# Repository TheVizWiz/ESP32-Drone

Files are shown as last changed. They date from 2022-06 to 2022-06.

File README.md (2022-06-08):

# ESP32 - Drone

### A Drone, Controller, and Flight Software, based on the popular ESP32 Microcontroller architecture.

## Current State
- Drone:  CAD model has been finalized and printed, as shown below. RF24 modules have been tested at distance, and motors and batteries have been mounted.
- Controller: PCB design is underway using multiplexers to extend ESP32 capabilities to more GPIO pins. RF24 module is being integrated, as well as battery circuitry.

### Drone Model
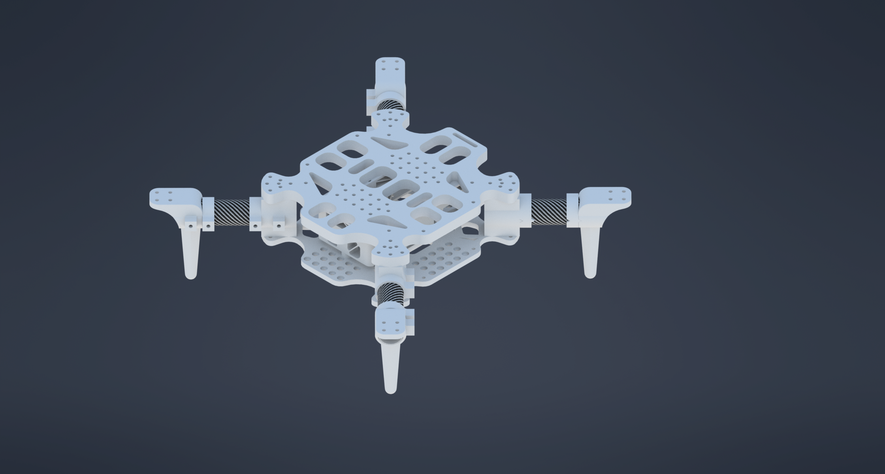
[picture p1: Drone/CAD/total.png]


### PCB Schematic
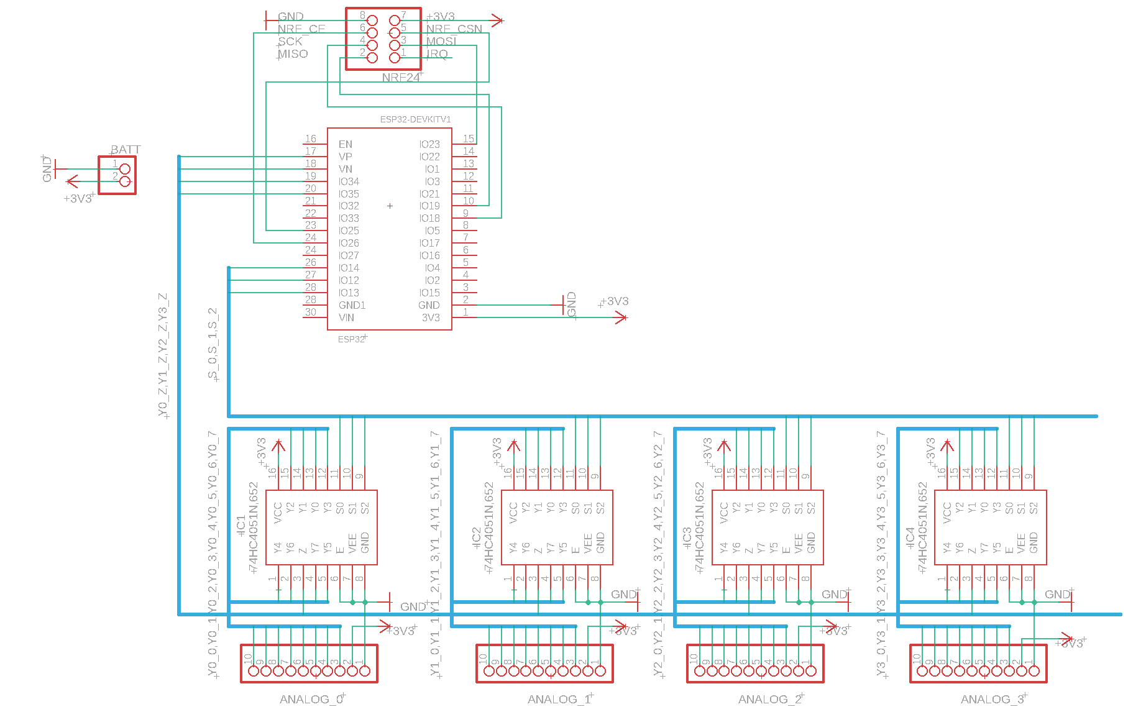
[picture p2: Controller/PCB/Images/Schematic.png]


## Overview
This is an ESP32-based from-scratch Drone project, meant to help learn the fundamentals of CAD, PCB design, control system software, as well as utilize the C++ programming language for high levels of multithreaded efficiency and performance. The Drone is built on a 4S cell system (14.8V), with 2200Kv motors (I would recommend going with a lower Kv value if you are reproducing this project, as that will be more efficient; I used what was on hand), and 10" propellers. It is designed to carry its own weight as well as a payload of ~1kg (2.2lb). 

## Project Objectives

### Drone
- Use Autodesk Inventor to design and 3D print a custom Drone body, built for carrying heavy weight (25+ kg).
- Utilize RF24 radio modules, as well as MPU6050 sensors, to build a real-time multithreaded flight control system, using PID control system algorithms.
- Create modular systems that allow for plug-and-play extension systems (eg. a payload-dropping and sensing system, as well as a front-mounted camera gimbal.)
- Build error-handling systems that allow for the easy handling of exception scenarios, such as loss of network signal or missed packets.
- Architecture system for Payload Acknowledge based telemetry, for use with flight telemetry / analysis software.

### Controller
- Use a secondary ESP32 system to measure input signals and relay to drone with RF24 modules.
- Utilize 74HC4051 ICs for breaking out signals, allowing for multiple expansion ports in the controller.
- Design and print controller body that allows for easy battery replacement and management, as well as easy access to controller ports for software updates. hook up GPIO_0 for easy boot access, as well as EN pin for reboots.

### Flight Software
- Use ElectronJS, ReactJS, and Victory Charts to create real-time telemetry for use on a desktop system.
- Build a Wifi-based connectivity system to relay information from drone to controller, package information, and then send asynchronously from controller to the host desktop system.
- Allow for multiple running systems and modes (sensing, graphs, console), as well as for reading data instead of only parsing from the drone. Further, use OpenGL and WebGL to render a 3D canvas view of the drone in flight.

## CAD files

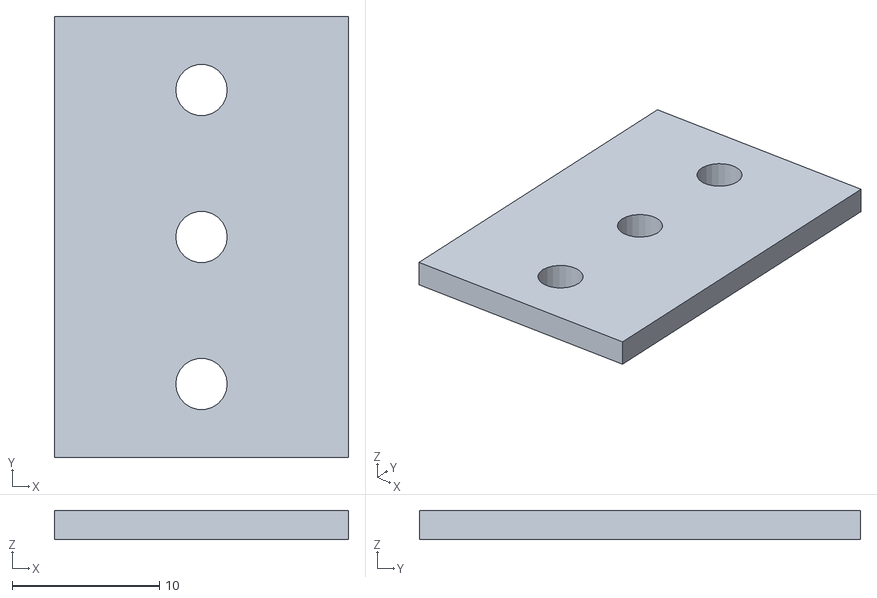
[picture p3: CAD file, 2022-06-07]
Drone/CAD/arm/top spacer.stl
20.0 x 30.0 x 2.00

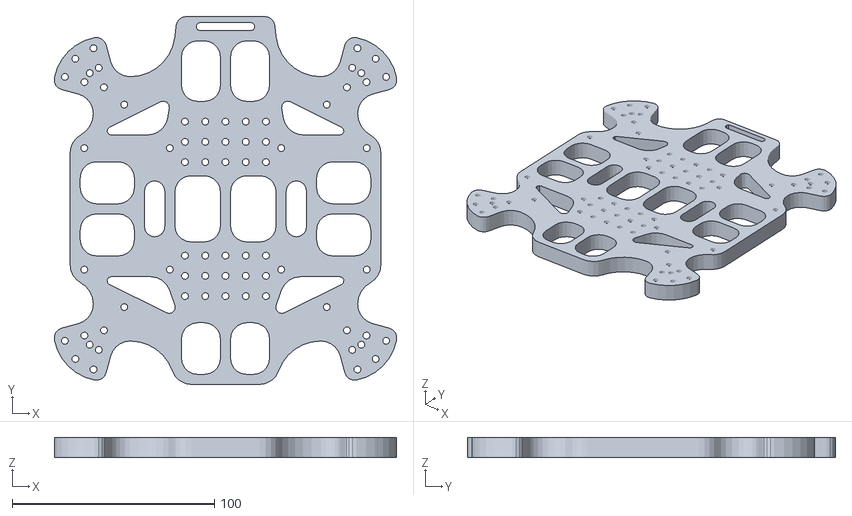
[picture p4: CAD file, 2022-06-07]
Drone/CAD/body/top.stl
169.1 x 181.8 x 10.0

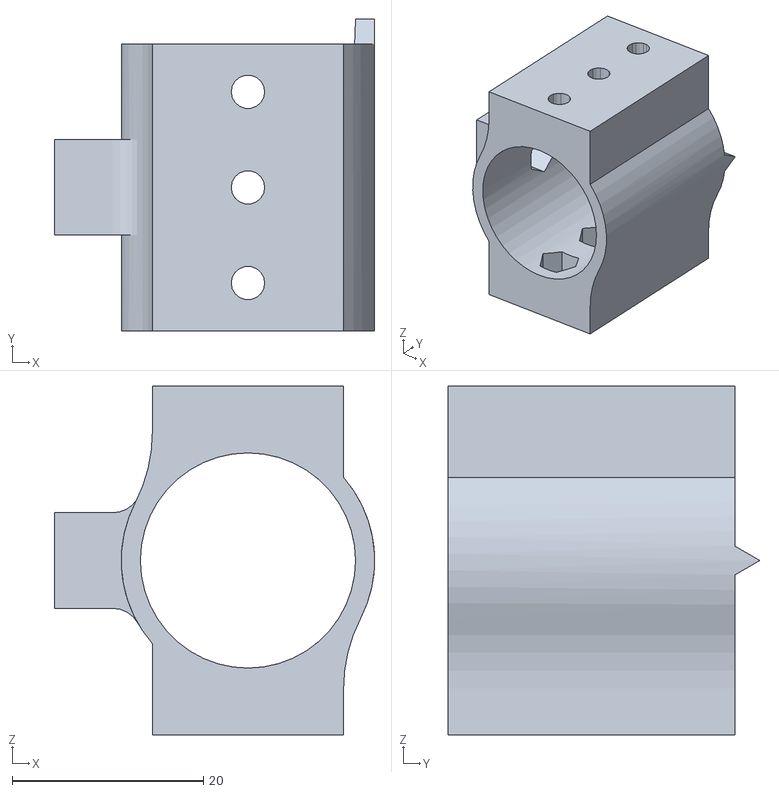
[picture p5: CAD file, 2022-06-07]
Drone/CAD/arm/body holder.stl
33.5 x 32.6 x 36.5

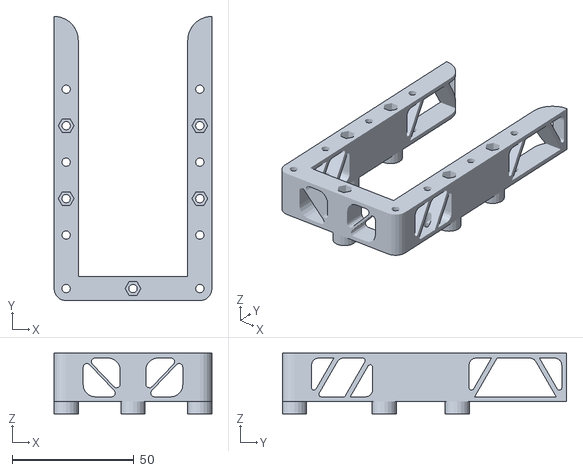
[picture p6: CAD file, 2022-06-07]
Drone/CAD/body/middle spacer bottom.stl
65.0 x 117.0 x 25.0

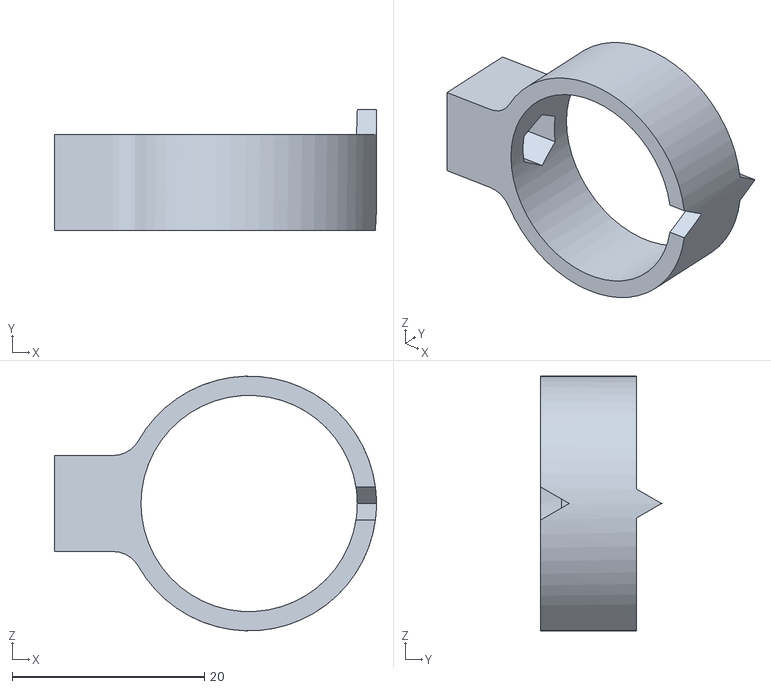
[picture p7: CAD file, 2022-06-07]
Drone/CAD/arm/arm indexer 1cm.stl
33.5 x 12.6 x 26.5

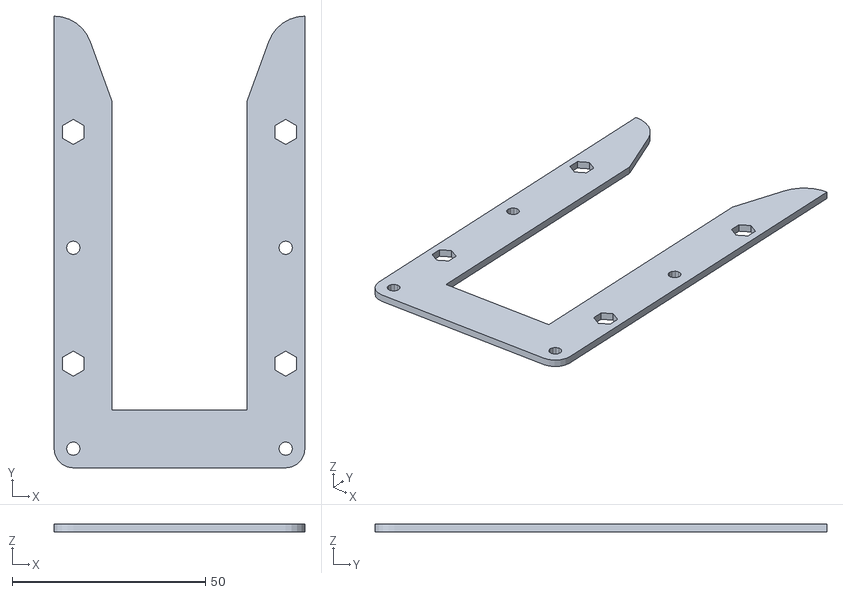
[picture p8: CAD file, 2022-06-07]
Drone/CAD/body/battery holder flap.stl
65.0 x 117.0 x 2.00

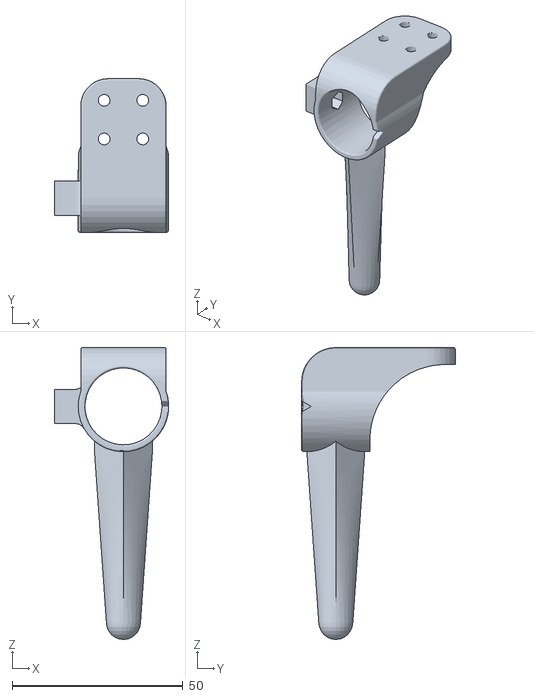
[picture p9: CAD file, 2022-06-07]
Drone/CAD/arm/motor holder.stl
33.5 x 45.0 x 85.5

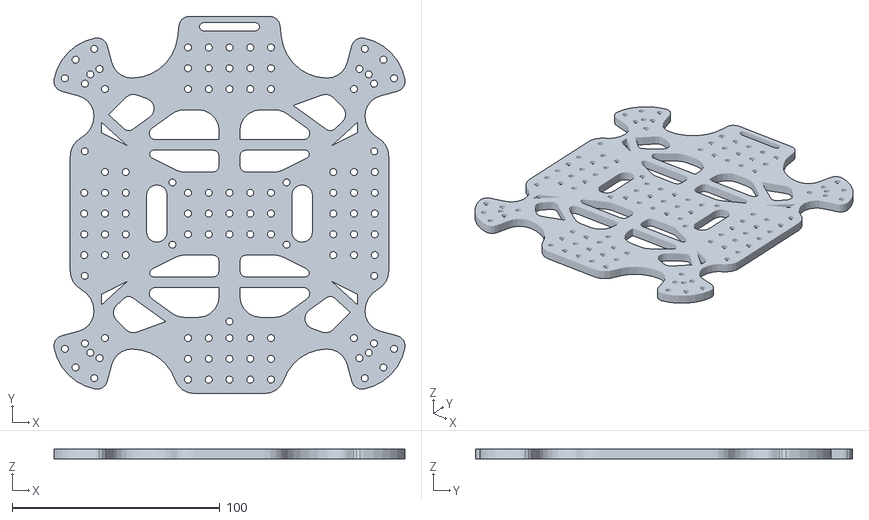
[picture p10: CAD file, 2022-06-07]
Drone/CAD/body/bottom.stl
169.1 x 181.8 x 5.00

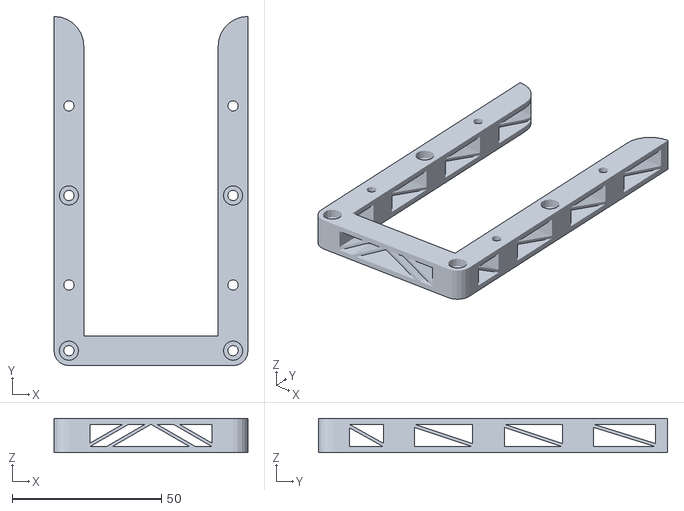
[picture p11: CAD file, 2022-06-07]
Drone/CAD/body/middle spacer top.stl
65.0 x 117.0 x 11.5

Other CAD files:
Drone/CAD/OldVersions/total.0029.iam
Drone/CAD/arm/OldVersions/_arm.0004.iam
Drone/CAD/arm/OldVersions/arm base piece.0001.ipt
Drone/CAD/arm/OldVersions/arm indexer 1cm.0003.ipt
Drone/CAD/arm/OldVersions/body holder.0003.ipt
Drone/CAD/arm/OldVersions/motor holder.0005.ipt
Drone/CAD/arm/OldVersions/top spacer.0001.ipt
Drone/CAD/arm/OldVersions/tube.0001.ipt
Drone/CAD/arm/_arm.iam
Drone/CAD/arm/arm base piece.ipt
Drone/CAD/arm/arm indexer 1cm.ipt
Drone/CAD/arm/body holder.ipt
Drone/CAD/arm/motor holder.ipt
Drone/CAD/arm/top spacer.ipt
Drone/CAD/arm/tube.ipt
Drone/CAD/body/OldVersions/battery holder flap.0002.ipt
Drone/CAD/body/OldVersions/bottom.0030.ipt
Drone/CAD/body/OldVersions/middle spacer bottom.0005.ipt
Drone/CAD/body/OldVersions/middle spacer top.0008.ipt
Drone/CAD/body/OldVersions/middle spacer.0001.ipt
Drone/CAD/body/OldVersions/top.0009.ipt
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

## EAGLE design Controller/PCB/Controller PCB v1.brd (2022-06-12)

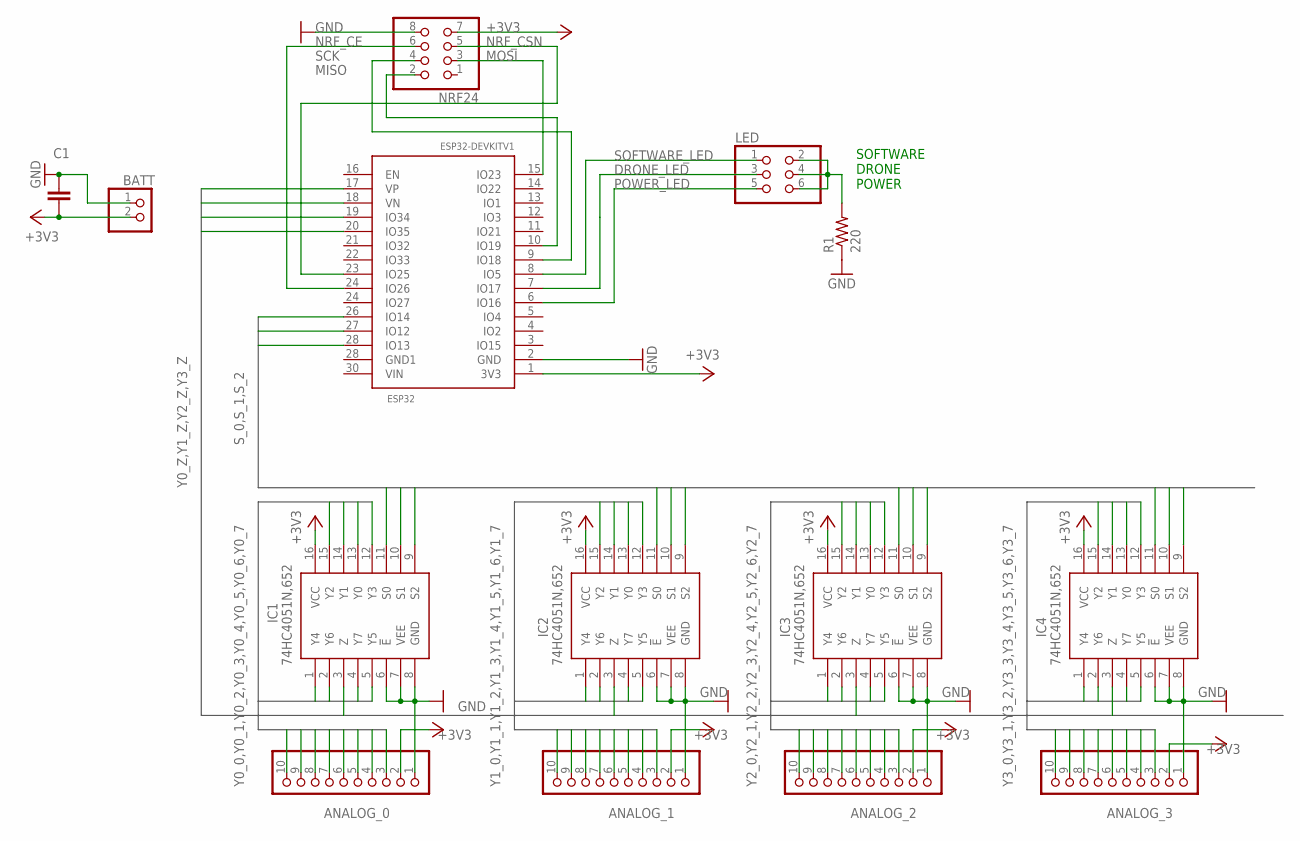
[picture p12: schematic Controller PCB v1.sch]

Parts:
ANALOG_0, ANALOG_1, ANALOG_2, ANALOG_3: PINHD-1X10/90; 1X10/90
BATT: PINHD-1X2; 1X02
C1: C2.5/2; C2.5-2
ESP32: ESP32DEVKITV1; ESP32-DEVKITV1
IC1, IC2, IC3, IC4: 74HC4051N,652; DIP802W53P254L1902H420Q16N
LED: PINHD-2X3; 2X03
NRF24: PINHD-2X4/90; 2X04/90
R1: 220; 0204/7

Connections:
+3V3: ANALOG_0.2, ANALOG_1.2, ANALOG_2.2, ANALOG_3.2, BATT.2, C1.2, ESP32.1 (3V3), IC1.16 (VCC), IC2.16 (VCC), IC3.16 (VCC), IC4.16 (VCC), NRF24.7
DRONE_LED: ESP32.7 (IO17), LED.3
GND: ANALOG_0.1, ANALOG_1.1, ANALOG_2.1, ANALOG_3.1, BATT.1, C1.1, ESP32.2 (GND), IC1.6 (!E), IC1.7 (VEE), IC1.8 (GND), IC2.6 (!E), IC2.7 (VEE), IC2.8 (GND), IC3.6 (!E), IC3.7 (VEE), IC3.8 (GND), IC4.6 (!E), IC4.7 (VEE), IC4.8 (GND), NRF24.8, R1.1
MISO: ESP32.10 (IO19), NRF24.2
MOSI: ESP32.15 (IO23), NRF24.3
unnamed: LED.2, LED.4, LED.6, R1.2
NRF_CE: ESP32.24 (IO27), NRF24.6
NRF_CSN: ESP32.23 (IO25), NRF24.5
POWER_LED: ESP32.6 (IO16), LED.5
SCK: ESP32.9 (IO18), NRF24.4
SOFTWARE_LED: ESP32.8 (IO5), LED.1
S_0: ESP32.28 (IO13), IC1.11 (S0), IC2.11 (S0), IC3.11 (S0), IC4.11 (S0)
S_1: ESP32.27 (IO12), IC1.10 (S1), IC2.10 (S1), IC3.10 (S1), IC4.10 (S1)
S_2: ESP32.26 (IO14), IC1.9 (S2), IC2.9 (S2), IC3.9 (S2), IC4.9 (S2)
Y0_0: ANALOG_0.3, IC1.13 (Y0)
Y0_1: ANALOG_0.4, IC1.14 (Y1)
Y0_2: ANALOG_0.5, IC1.15 (Y2)
Y0_3: ANALOG_0.6, IC1.12 (Y3)
Y0_4: ANALOG_0.7, IC1.1 (Y4)
Y0_5: ANALOG_0.8, IC1.5 (Y5)
Y0_6: ANALOG_0.9, IC1.2 (Y6)
Y0_7: ANALOG_0.10, IC1.4 (Y7)
Y0_Z: ESP32.17 (VP), IC1.3 (Z)
Y1_0: ANALOG_1.3, IC2.13 (Y0)
Y1_1: ANALOG_1.4, IC2.14 (Y1)
Y1_2: ANALOG_1.5, IC2.15 (Y2)
Y1_3: ANALOG_1.6, IC2.12 (Y3)
Y1_4: ANALOG_1.7, IC2.1 (Y4)
Y1_5: ANALOG_1.8, IC2.5 (Y5)
Y1_6: ANALOG_1.9, IC2.2 (Y6)
Y1_7: ANALOG_1.10, IC2.4 (Y7)
Y1_Z: ESP32.18 (VN), IC2.3 (Z)
Y2_0: ANALOG_2.3, IC3.13 (Y0)
Y2_1: ANALOG_2.4, IC3.14 (Y1)
Y2_2: ANALOG_2.5, IC3.15 (Y2)
Y2_3: ANALOG_2.6, IC3.12 (Y3)
Y2_4: ANALOG_2.7, IC3.1 (Y4)
Y2_5: ANALOG_2.8, IC3.5 (Y5)
Y2_6: ANALOG_2.9, IC3.2 (Y6)
Y2_7: ANALOG_2.10, IC3.4 (Y7)
Y2_Z: ESP32.19 (IO34), IC3.3 (Z)
Y3_0: ANALOG_3.3, IC4.13 (Y0)
Y3_1: ANALOG_3.4, IC4.14 (Y1)
Y3_2: ANALOG_3.5, IC4.15 (Y2)
Y3_3: ANALOG_3.6, IC4.12 (Y3)
Y3_4: ANALOG_3.7, IC4.1 (Y4)
Y3_5: ANALOG_3.8, IC4.5 (Y5)
Y3_6: ANALOG_3.9, IC4.2 (Y6)
Y3_7: ANALOG_3.10, IC4.4 (Y7)
Y3_Z: ESP32.20 (IO35), IC4.3 (Z)

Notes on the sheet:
SOFTWARE DRONE POWER

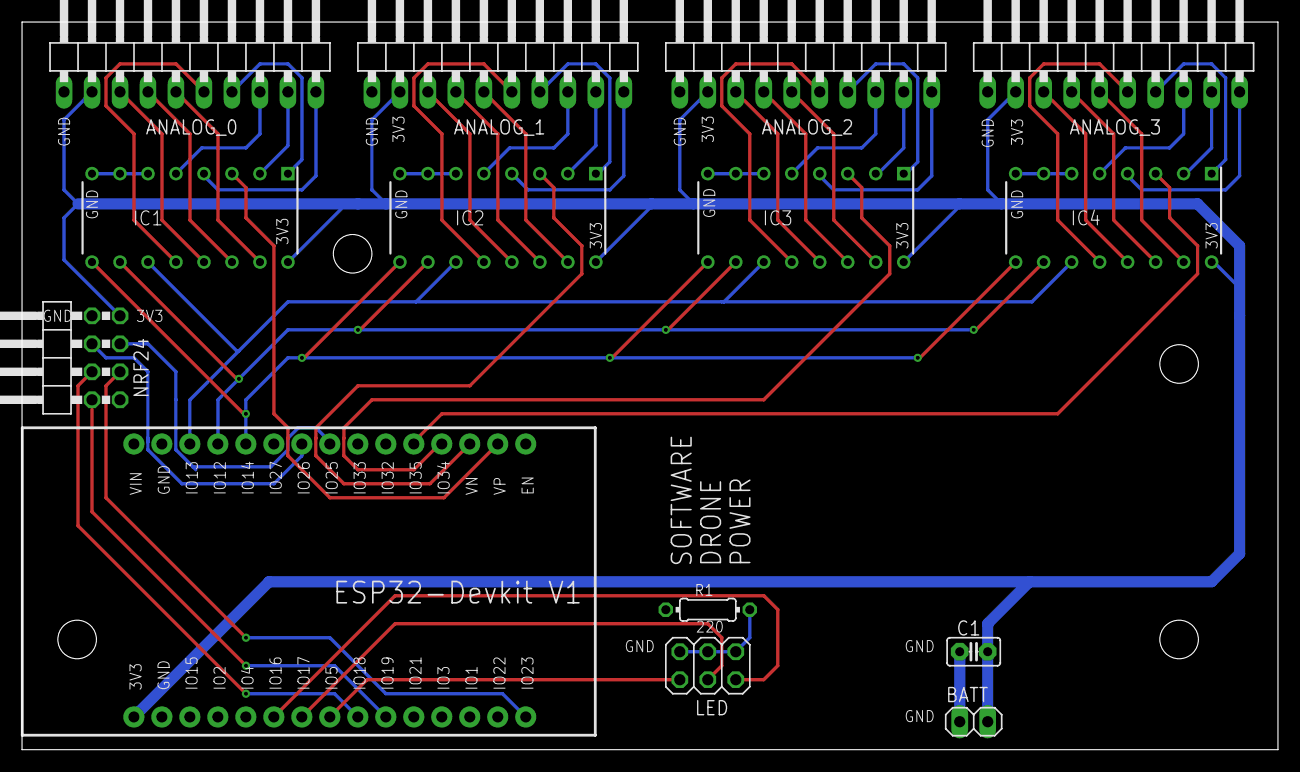
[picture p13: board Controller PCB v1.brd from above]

Board: 2 copper layers, 114.0 x 66.0 mm, 14 parts (0 on the bottom side), 50 nets.

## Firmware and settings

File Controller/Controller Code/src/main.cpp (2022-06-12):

#include <Arduino.h>
#include <ESPAsyncWebServer.h>
#include <ArduinoJson/Document/DynamicJsonDocument.hpp>
#include "RF24.h"
#include "AnalogMux.cpp"
#include "Packet.h"
#include "main.h"


#define s_0 1
#define s_1 2
#define s_2 3
#define z_0 4
#define z_1 5
#define z_2 6
#define z_3 7

#define RADIO_CE_PIN 26
#define RADIO_CS_PIN 25

AnalogMux
		mux1 = AnalogMux(s_0, s_1, s_2, z_0),
		mux2 = AnalogMux(s_0, s_1, s_2, z_1),
		mux3 = AnalogMux(s_0, s_1, s_2, z_2),
		mux4 = AnalogMux(s_0, s_1, s_2, z_3);

ControllerPacket controllerData = ControllerPacket();
TelemetryPacket droneData = TelemetryPacket();

RF24 radio = RF24(RADIO_CE_PIN, RADIO_CS_PIN);
byte radioAddress[6] = "00001";


const char *ssid = "arduinoWifi";
AsyncWebServer server(80);
AsyncWebSocket socket("/ws");
char jsonSerialized[2048];
ArduinoJson6194_F1::DynamicJsonDocument jsonDocument(2048);


void setup () {
	Serial.begin(115200);


	radio.begin();
	radio.setPALevel(RF24_PA_LOW);
	radio.setDataRate(RF24_1MBPS);
	radio.setChannel(0);
	radio.enableAckPayload();
	radio.openWritingPipe(radioAddress);
	radio.stopListening();

	WiFi.softAP(ssid);

	// Print ESP Local IP Address
	Serial.println("IP: " + WiFi.softAPIP().toString());

	server.addHandler(&socket);


	// Route for root / web page
	server.on("/", HTTP_GET, [] (AsyncWebServerRequest *request) {
		parseInput();
		request->send(200, "application/json", jsonSerialized);
	});

	// Start server
	server.begin();

// write your initialization code here
}

void loop () {

	parseInput();
	radio.write(&controllerData, sizeof(controllerData));

	if (radio.isAckPayloadAvailable()) {
		radio.read(&droneData, sizeof(droneData));
	}

	socket.textAll(jsonSerialized);
	socket.cleanupClients();

}

void parseInput () {

}

void writeJSON () {
	jsonDocument["pitch"] = ;

}

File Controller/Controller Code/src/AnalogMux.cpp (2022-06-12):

//
// Created by vibhu on 6/9/2022.
//

#include "AnalogMux.h"
#include "Arduino.h"


AnalogMux::AnalogMux (int s_0, int s_1, int s_2, int z) : AnalogMux(s_0, s_1, s_2, z, INPUT) {
}

AnalogMux::AnalogMux (int s_0, int s_1, int s_2, int z, int inputMode) {
	this->s_0 = s_0;
	this->s_1 = s_1;
	this->s_2 = s_2;
	this->z = z;
	pinMode(s_0, OUTPUT);
	pinMode(s_1, OUTPUT);
	pinMode(s_2, OUTPUT);
	pinMode(z, inputMode);

}

bool *AnalogMux::digitalReadAll () {
	bool reads[8];
	for (int i = 0; i < 8; ++i) {
		reads[i] = digitalRead(i);
	}
	return reads;
}

uint16_t *AnalogMux::analogReadAll () {
	uint16_t reads[8];
	for (int i = 0; i < 8; ++i) {
		setMux(i);
		reads[i] = Arduino_h::analogRead(z);
	}
	return reads;
}

void AnalogMux::setMux (int signalNumber) {
	digitalWrite(s_0, (signalNumber & 1) ? HIGH : LOW);
	digitalWrite(s_1, (signalNumber & 2) ? HIGH : LOW);
	digitalWrite(s_2, (signalNumber & 4) ? HIGH : LOW);
}

bool AnalogMux::digitalRead (int signalNumber) {
	setMux(signalNumber);
	return ::digitalRead(z);
}

uint16_t AnalogMux::analogRead (int signalNumber) {
	setMux(signalNumber);
	return ::analogRead(z);
}

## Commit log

2022-06-08 pcb work
    [Controller PCB v1.brd, Controller PCB v1.sch, total.0028.iam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]
2022-06-12 pcb work, controller code work
    [Controller PCB v1.brd, Controller PCB v1.sch]
